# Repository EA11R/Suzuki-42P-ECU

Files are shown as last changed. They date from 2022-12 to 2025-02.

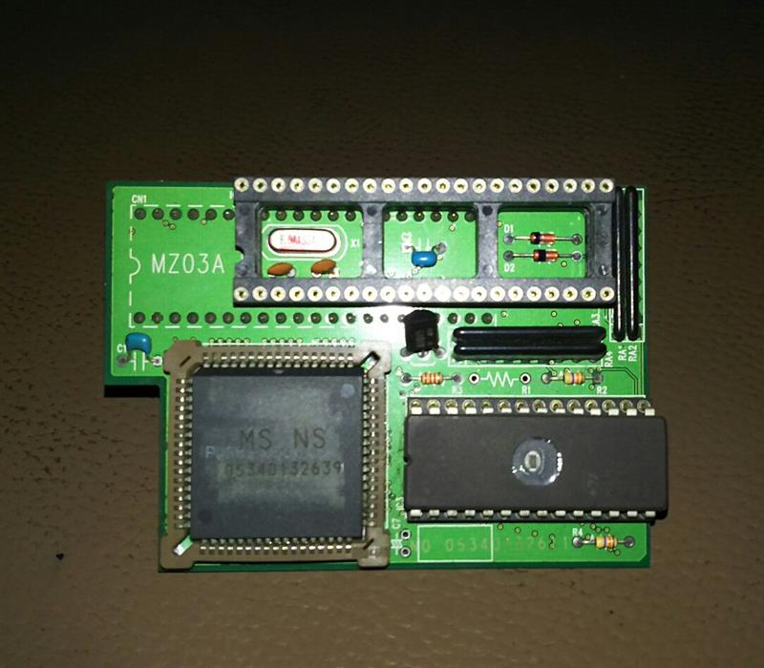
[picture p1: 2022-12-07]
TECHTOM/IMG_0491.JPG

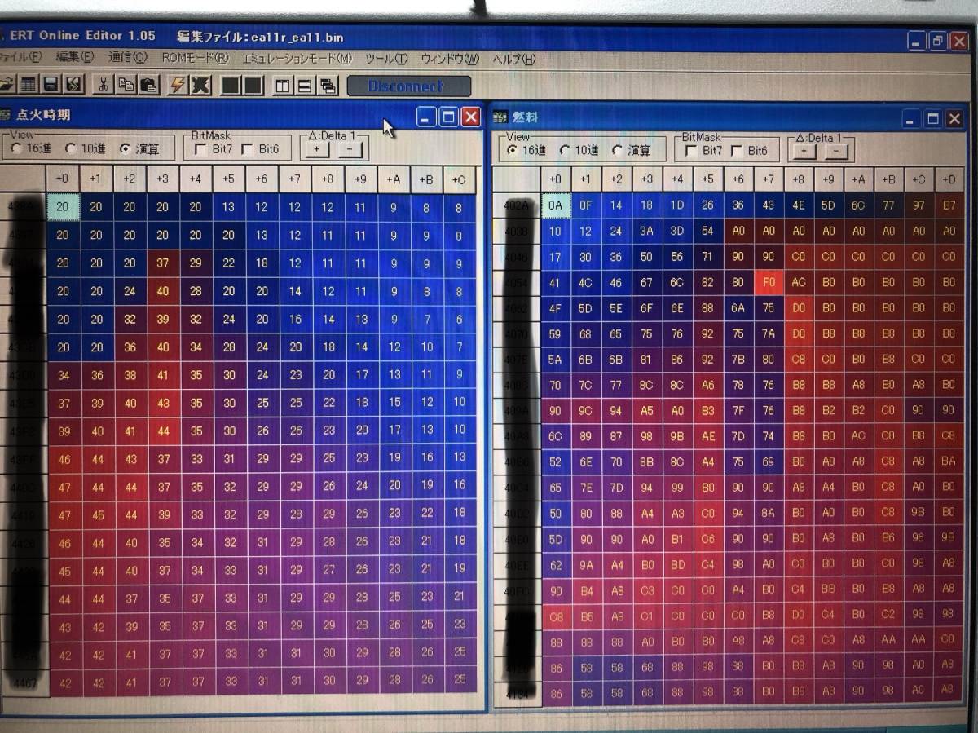
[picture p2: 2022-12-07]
TECHTOM/i-img1200x899-1564741742y9fy37383216.jpg

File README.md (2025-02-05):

# Suzuki-42P-ECU
The #1 source of Suzuki mask MPU information and resources 
 ## image of board 
 
 i-img1200x903-1666231880i3cpzc833943

 the board utilzes a 8-bit cpu which is masked it's believed to be close 
 
 > the pinout has been previously figured out by (rhinopower) 
 www.rhinopower.org/ECUs/RomReader/Romreader.html
 
 ## pinout of the cpu 
  IMG_0691_result

## about [*IC101*]
the raw sensor input connects to IC101 before being converted to digital signals 
and sent to CPU on the Right side of the IC the raw inputs could be sniffed as a 0-5v
analog signal.

> this is a pinout of the ecu pulled over by a scope and some testing 
I took the neccesary pins of it to work and left over things such as temp sensors 
it can be pulled out of the ecu but I honestly can't tell how to turn that digital signal into numbers without further testing
the IC before it however has a gradiant signal of voltage via the variant resistance of the temp thermos 
I have took the neccesary pins to hook the ECU alongsite a daughter card that uses speeduino 

## Current Daugtercards on sale
   MTR40BB : https://buyee.jp/item/yahoo/auction/u1052820291
   
   QSF313_F6A : https://github.com/EA11R/Suzuki-42P-ECU/tree/main/QSF_ADD_ON_BOARD

## Possible piggy-back ECU's
- E-manage (TRUST)

- HKS F-con (ALL)

- Speeduino ( can be standalone with some changes)

- any ECU that can get a squarewave signal and a choice of cylinders.
Current ("Free of charge") project

- an open source ECU adapter for speeduino boards & harness how to and links to purchace parts 

- Adapter PCBS for popular ecus with an added pip373 slot for distrubtor ignition!

- Modren Daughtercard using oem CPU + speeduino (atmega 2560) , for better ignition timing , full fuel control

> Prepare for Piggyback install : 


 - 1 Cut the resistor where I have the solder joint from the middle so you can Undo if you wish. 
     then pass the wires trough the case holes
  
 -  2 Solder the wire onto the remaining of the resistor leg. & lift it up to keep space * this will be your "out wire" from stock to aftermarket
 
  - 3 shrink tube the resistor is a good countermeasure just incase the resistor vibrates back into place , any insulator is fine.
 
 -  4 solder a IN wire in the remaining of the other side. ( connect the wire coming from aftermarket to your stock ecu)
  
  >  the rest of the information will be on each independant ecu catagory with it's own install guide.

## Repair 
- As far as repair goes within the suzuki ecu
if you manage to burn the cpu or the IC101 you need another suzuki ecu as a donor to fix that 
otherwise all other parts can be found off shelf 
the similar ICs are AD chips.

## My PNP Card Design 
converts the OEM stock ECU into a tuneable 
ECU and adds a Addtional injection channel 
to convert fueling into fully sequential

Features:

-Internal MAP option 

-wideband support 

-Ignition control (optional)

-Bluetooth 

-Data logging (bluetooth or usb)



## PDF Resources & Notes

| ECU | PDF/DIR  |
| --- | --- |
| QSF_F6A |[Directory](QSF_ADD_ON_BOARD/readme.md)
| HKS F-CON IS Pinout |[Click Here](HKS_F_CONV_&_IS/F-conIS.jpg) |
| HKS F-CON IS Installion Notes |[Click Here](HKS_F_CONV_&_IS/installation%20notes.md) |
| E-Manage (TRUST) |[Directory](E-manage/) |
| MCU & EPPROM's |[Directory](Datasheet/)
| MTR40BB |[Directory](MTR40BB%20INFORMATION/)
| Speeduino |[Directory](speeduino/)
| Distributor_wheel |[Directory](Distributor_Modification/readme.md)

So lets see where this project goes and the documentation with it shall we 

**Qatif Speed Factory , Saleh.M**

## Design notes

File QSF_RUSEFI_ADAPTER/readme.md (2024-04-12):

## RUSEFI UAEFI BASED SUZUKI EMS 
as rusefi expanded into making better and better ecus over the years , they've released the affordable verison of their lineup and that is way over what the cappuccino needs to run since it's a 6x6 ecu
therefore many of the outputs can be reutilized for other things and I took advantage over the fact to create a true "ULTRA AFFORDABLE CAPPUCCINO ECU" without going low on features 

## For people with bare stock cars
just plug the ecu and turn the key it will function as is and perform superior to stock it will come with a base tune that can run the car 
daily , and without the annoying fuel cut , engine rev limiter will come configured @9000 rpm to cut spark only and without any boost limitation 
or speed however with needs to upgrade turbo , injectors etc , you can dive into the depths of this manual.

## for nerds 
you can get the adapter from me and solder the ecu board from RUSEFI yourself 
I recently changed my pin size to arduino (0.8MM) on adapter side due to 1.14MM pins being difficult to source and expensive 
would increase cost by 60$

## IMAGE OF BOARD





## COP HARNESS EXPLAINED 


## WARNING 
please use orignal IG power to power ur coil pack harness instead of direct ecu feed 
don't use 12V on ecu extra plug to feed it with power as I only use them for testing

## Wiring order
**IGN 1 = CLY 1** 

**IGN 2 = CLY 2**

**IGN 3 = CLY 3**

each number goes to it's co-responding cylinder don't be afraid to mismatch because it can be managed in software 
for GND of coils it should be grounded somewhere in the engine , anywhere you wish as long as it's a good ground 

## TACHOMETER
for tach signal I suggest some aftermarket cop tach adapters 
such as this if you're running "smart coils without a external ignitor" https://www.ebay.com/itm/142171581596 

and one such as this https://www.autosportlabs.com/product/tach-adapter/ for dumb coils!

**if you're running dumb coils with a external ignitor , you simply connect the coil minus side of ignitor and not the ecu signal side**
that piece will collect all grounds and will send a signal back to your orignal tach without taking it out and modfiying it 
the cappuccino tachometer is similar to many toyotas of that era since it's denso made!
before connecting "TACH" to your orignal brown wire (coil ground) cut the IGN jumper shown below


## WARNING 
DO NOT AT ANY CIRCUMSTANCE PLUG A DUMB COIL DIRECTLY INTO THE COP HARNESS USE A IGNITOR BOARD BOUGHT NEW OR SALVAGED FROM A YARD , HERES SOME OPTIONS SO YOU DON'T SMELL FUNNY ELECTRONICS OR LOSE 300$ IN THE BIN 
## IGNITOR SUGGESTIONS 
 

Nissan igntiors

 

toyota igntior 



bosch (0 227 100 200) 3 channel



basically any ignitor set that can fire 3 coils would be ok for smart coils you won't need a ignitor obviously 

## IGN JUMPER 


**make sure to cut jumper made here , and remove solder from the SMD jumper , the THT jumper is there if you somehow manage to ruin the SMD jumper however it's nice to have both closed when running stock coil to insure it's getting a good signal** 

orignal harness side coil plug 
https://www.aliexpress.com/item/1005002422920931.html
needed to make a COP plug , source whatever coils u want ur self , and take care of the bracket

## WARNING 

if you don't cut IGN jumper or remove IGN#1 wire from ecu plug this before install of coil packs you can risk damage to your tach or ecu while installing tachometer adapter 
tach adapters have voltage spikes up to 60V and I don't suggest back feeding it into your ignition transistor as it shouldn't share the signal with IGN#1 
anymore

## AUX 1 (one of 3 AUX WIRES across the board)
it's a gauge input bundled with the COP plug you can use that to put any analog gauge u wish into ur ecu
if ur running a stock setup and want to have a full digital cluster I suggest using it for fuel level!
AUX1 can be used for a external wideband that isn't CAN based but I suggest using it for something more useful
such as oil temp or pressure along with the other AUX gauges
## Ask for help you're not superman!
again if you don't have knowledge in wiring don't be afraid to ask me or consult your local wiring/ecu speicalists 
just hand them this information and they will certianly understand why and how!

## CAS HARNESS EXPLAINED 



as simple as it gets wire each one into it's counterpart in the CAS sensor on ur daewoo distributor 



## KNOCK SENSOR (IN CAS HARNESS BECAUSE IT'S CLOSE TO THE BOTTOM OF THE ENGINE)
for knock sensor check the diagram of whatever sensor ur using 

wire signal to KNOCK_IN

wire ground to GNDA 

## CAN BUS HARNESS 



CAN + , CAN - can be used to wire a external wideband such as AEM Series X , you can certianly use the onboard wideband if you don't want/need a gauge

BTN2 (ORIGNALLY USED FOR A/C) (can be reutilized for race cars) , BTN3,BTN1 can be used as a clutch switch or any kind of button to activate anything 

**BUTTONS (GROUND BASED SWITCH OR BUTTON ONLY)**

## E-Throttle + TPS information 


| PIN | FUNCTION |
| --- | --- |
| DC1 +  | Throttle motor + |
| DC1 - | Throttle motor -  |
| TPS1  | TPS SIGNAL|
| TPS2  | TPS SIGNAL(only E throttle uses two tps)|
| GNDA | I think ground O_0 but for sensor (use for tps) |
| 5V | I think FIVE VOLTS use for tps power |
| fun fact | TPS 5V being connected with any 12v wire will kill ur ecu |

| PIN | FUNCTION |
| --- | --- |
| PPS1  |Primary pedal output|
| PPS2 | secondary pedal output|

| EXTRA PIN | FUNCTION |
| --- | --- |
| LSW1  |LOW SIDE OUT (can used for fan relay)|
| BTN1 | BUTTON OR SWITCH INPUT (GROUND BASED ONLY) |



| EXTRA PIN | FUNCTION |
| --- | --- |
| IGN5 (TACH)  |TACHOMETER OR WHATEVER OUTPUT U WANT|
| AUX3 | ANALOG GAUGE INPUT (0-5V) |

**IF YOU EVER WANTED STEPPER IDLE**

| DC PIN | FUNCTION |
| --- | --- |
| DC2+  |STEPPER +|
| DC2- | STEPPER- |

## NEW ECU PINOUT AND EXTRAS 



the unused pins in the harness are now INJ3 (For sequential use) and FLEX (Flex fuel sensor) 
EL1 , EL2 are dropped from harness (unconnected) 
EGR No longer used (always off) 

## supported Triggers 

| TRIGGER | RECOMMENDED |
| --- | --- |
| EA11R STOCK 3 TOOTH |works but very low res (single coil only) |
| Daewoo Distributor | recommended for single coil and COPs|

## for nerds read: 

| Distributor_wheel |[Directory](https://github.com/EA11R/Suzuki-42P-ECU/blob/main/Distributor_Modification/readme.md)|
| --- | --- |

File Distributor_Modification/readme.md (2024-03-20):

Modification of the Disitributor or installation of a crank trigger wheel is a basic Requirment of Running a Aftermarket EFI unit on your suzuki
sometimes those options could be a little expensive so heres some options you can reside to!

[OPTION #1] a replacment trigger wheel by link JP

Distrubtor wheel 24-1 Link JP (KTD F6CG) 
 
 F6CG TRIGGER(FITS INSIDE OEM CASE)

[OPTION #2] Honda 24 Distributor wheel modification 
Parts needed:

Honda D ,K series Distrubtor from junk
Hall crank sensor 
Cherry GS101205 HALL effect sensor 
Note : you need a 1k ohm resistor between VCC (5v+) and out (Signal) 

* you might be able to stay with the stock VR signal pickup but i have not tested if it could read a stable signal!
* wouldn't hurt to try either.





[OPTION #3] a TDC tooth on cam ( check the E-manage Section)

[OPTION #4] Crank wheels (some kind people within this community have done free files)
I will get time to do a write up on those too!

[OPTION #5] Daewoo matiz distributor 
it fits on the cappuccino directly , the cappuccino cap also fits over 
can use a R32 crank sensor if you remove it off the case it bolts right on 
it can also use a AEM 24-1 disc if you wish!
my rusefi based ecu can support stock GM trigger

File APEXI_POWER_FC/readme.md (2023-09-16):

Converison of RB26 Harness to work with the F6A engine 

Basic knowledge about how similar inline 6 engines are to inline 3

I6 : Piston 1,6 2,5 3,4 are paired together 
I3 : Piston 1,3,2 each on it’s own 

Firing order of an I6: 1-5-3-6-2-4 every cycle 

Firing order of an I3 : 1-3-2 every cycle 

so we understand that the I6 fires 6 times every full rotation
and the inline 3 fires 3 times every full rotation
so those aren’t matching in terms of fire

However if we skip 1 coil (piston in the cycle ) we get the half

(1-skip-3-skip-2-skip) we right now have a suitable ignition! 

IMG_C7B1C2669041-1

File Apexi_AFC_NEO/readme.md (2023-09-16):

Piggy back solution to trick the map sensor into reducing/adding more fuel 
can be helpful when installing larger injectors on stock ecu!
or simply for adding more fuel to your engine for more boost without the hassle 
or price of a standalone or chipped (suzuki sport ecu)

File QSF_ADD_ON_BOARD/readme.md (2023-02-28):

## Details about my Daughtercard for the F6AT ecu (K1)



Since the simplcity of the stock ecu Throttle switch I've decided to link it using a 5v signal from the actual ecu pinout so only WOT would effect the signal however if you wish to cancel this and add a virable nissan TPS you could unsolder the JP2 and connect it to the TPS pin shown within this photo
this should allow the tps to be utilized to be used for accel enrichment 

the map sensor can be connected via ADC chip but the better choice is to use the internal map sensor to control fueling in the system

#R504 can be connected to IG1 (**H1** on the board) to control the Ignition Advance however deleting the fuel cut is what is needed to add more boost 

there's extra circuit that could be built under the MPU to add a third injection channel to fully sequentially control the fuel on the engine 
so it becomes a single injection channel for each injector instead of the paired wire #20 on the oem harness 
------------------------------------------------
 **FEATURES** 
------------------------------------------------

1- On Board boost control ( requires a external solenoid) 
Ran via PWM signal 

2- Wideband support over the same wire (OX signal) 

3- Third Injection Channel 

4- Usage of full range TPS for accel enrichment 

5- External tach RPM wire (12v)

------------------------------------------------
**Third Injection channel**
------------------------------------------------
A Twin wire harness can be wired straight from the board to the injector #3 
This modification will convert the injection system to fully sequential 

** Ignition Advance control **
However it's very limted and not actually that useful but it's still possible 
I strongly advise just sticking to moving the distrubutor to adjust the timing or
buying viarable cam gears however adjusting small increments on higher boost could be done
over computer

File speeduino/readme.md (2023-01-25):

](https://wiki.speeduino.com/en/boards/V04) WIRING PINOUT

KEEPING THE RESISTOR IN PLACE AND SOLDERING THE SAME SPOT AS THE EXAMPLE IMAGE WILL ELEMINATE SPEEDUINO IGNTION CONTROL!
USEFUL WHEN RUNNING A EXTERNAL CDI OR JUST ADJUSTING FUEL.
IG_SPEEDUINO

this is the way to wire it up with ignition control

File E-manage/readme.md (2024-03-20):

| Title | Link |
| --- | --- |
| TDC adjustable cam trigger + E-manage setup information  |  [Click Here](https://factoryryo.web.fc2.com/factoryryo/specialtune/specialtune32.htm) 
| Japanese wiring diagram |  [Click Here](https://minkara.carview.co.jp/userid/17619/blog/1461248/)  |
| Jumper Informaiton for E-MANAGE BLUE |  [Click Here](https://minkara.carview.co.jp/userid/522838/car/457922/1506196/note.aspx) |

note Injectors are flipped 10# , 20# I had my harness plug flipped and this was based on a previous install
so on a normal car #10 is 1,2 and #20 is cly 3 on it's own! 

**flip injector light blue and yellow if you're following this for a install**



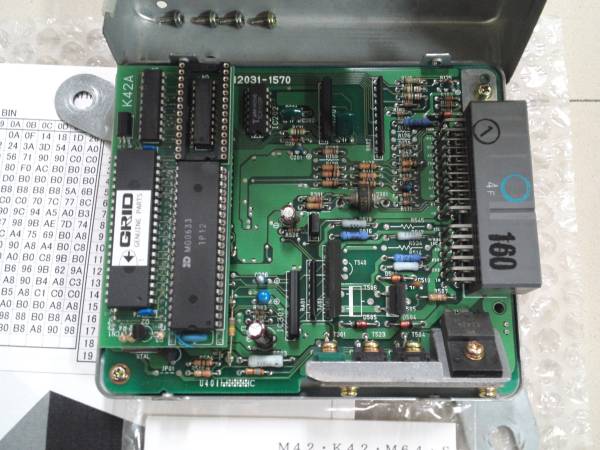
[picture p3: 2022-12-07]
GRID/d162023006.2.jpg

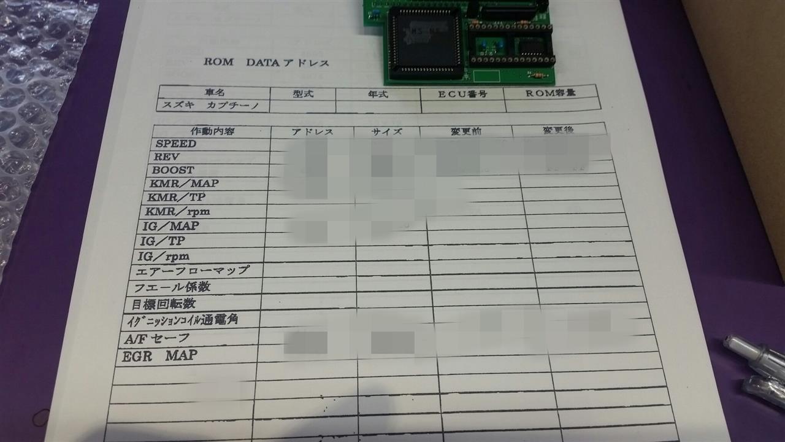
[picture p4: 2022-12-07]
TECHTOM/2167e978b1.jpg

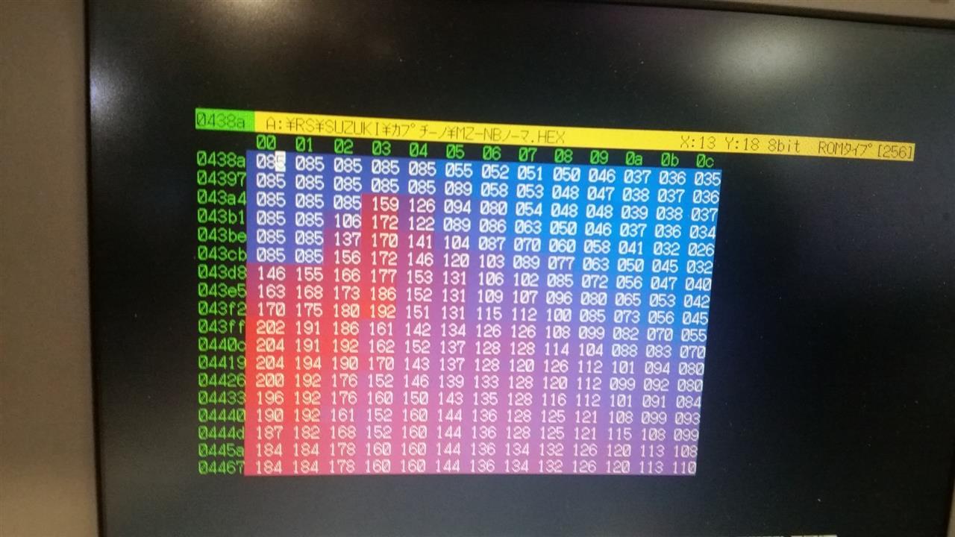
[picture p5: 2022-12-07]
TECHTOM/cb408cf9b0.jpg

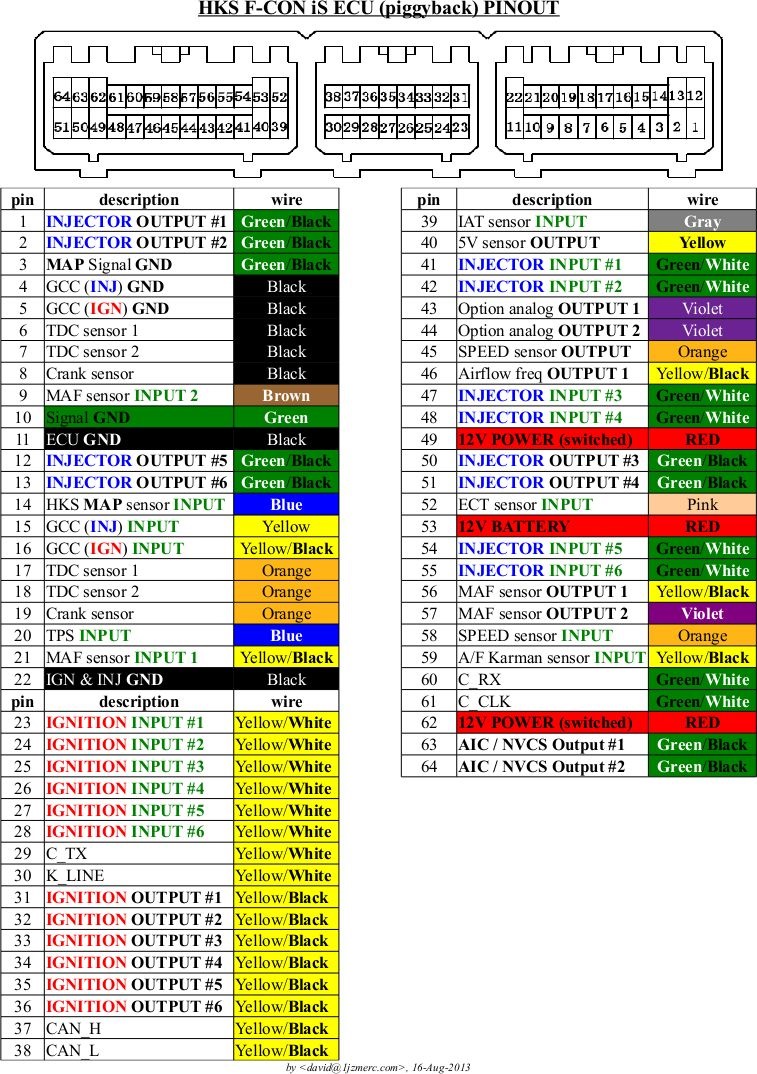
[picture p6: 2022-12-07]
HKS_F_CONV_&_IS/F-conIS.jpg

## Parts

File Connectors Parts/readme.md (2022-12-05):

## 22 PIN CONNECTOR 174913-6 ,174515-1
https://aliexpress.com/item/4001286921974.html 

## 12 PIN CONNECTOR  917989 , ? 
https://aliexpress.com/item/1005003760250270.html

## 34 PIN MAIN 
175444-6 TYCO 34 POSITION MULTILOCK I/O HYBRID CONNECTORS
https://aliexpress.com/item/1005003569743487.html

## PREBUILT EXT HARNESS 
https://buyee.jp/item/yahoo/auction/c1073995630

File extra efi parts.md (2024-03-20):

Distrubtor wheel 24-1 
Link JP (KTD F6CG)
http://www.linkecu.co.jp/products/detail/71

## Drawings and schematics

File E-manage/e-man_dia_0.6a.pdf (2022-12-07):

# は割り込み

# e-manage Ultimate wiring diagram

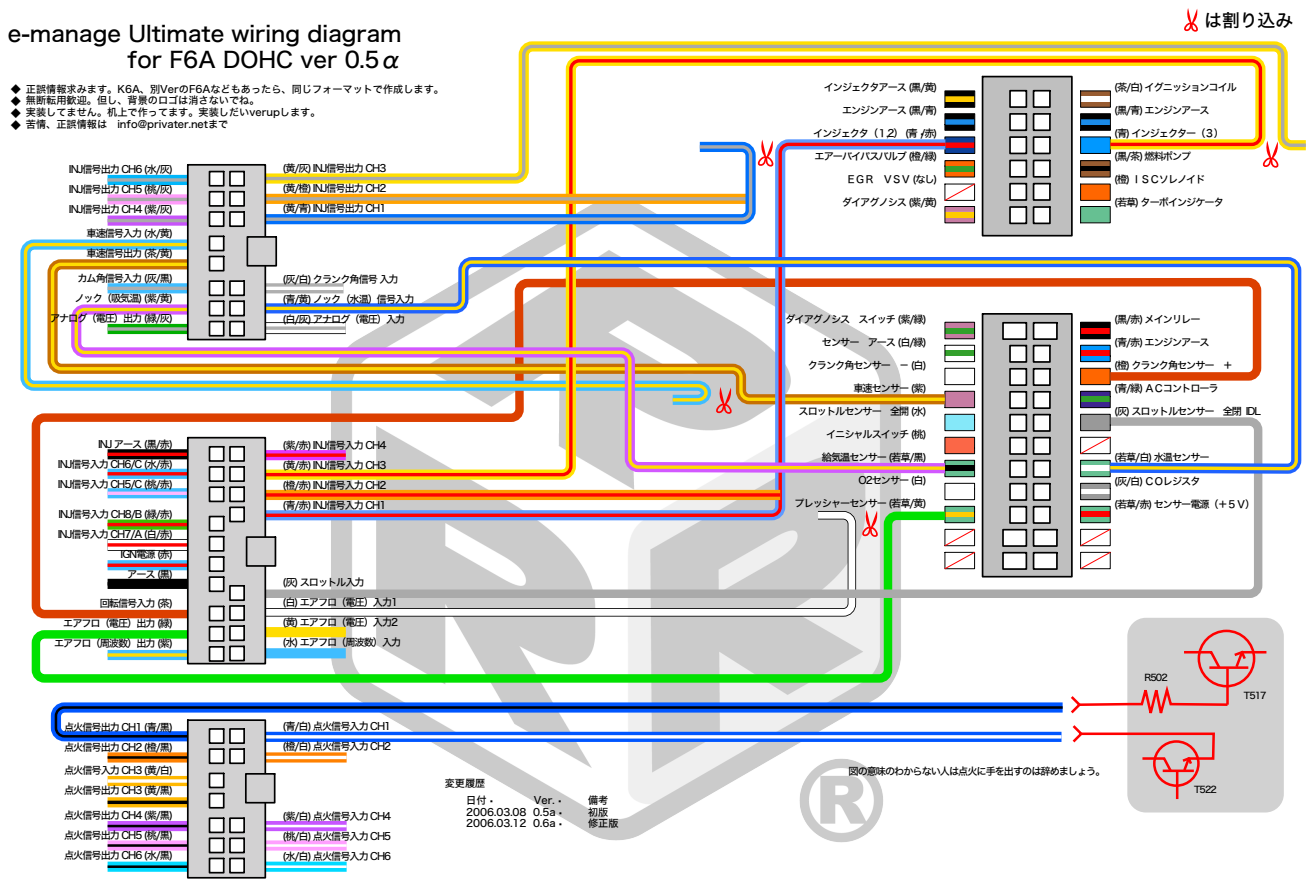
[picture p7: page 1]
図の意味のわからない人は点火に手を出すのは辞めましょう。; インジェクタアース(黒/黄); エンジンアース(黒/青); インジェクタ（１,2）(青/赤); エアーバイパスバルブ(橙/緑); ダイアグノシス(紫/黄); (茶/白)イグニッションコイル; (黒/青)エンジンアース; (青)インジェクター（３）; (黒/茶)燃料ポンプ; (橙)ＩＳＣソレノイド; (若草)ターボインジケータ; ダイアグノシス スイッチ(紫/緑); センサー アース(白/緑); クランク角センサー －(白); 車速センサー(紫); スロットルセンサー 全開(水); イニシャルスイッチ(桃); 給気温センサー(若草/黒); O2センサー(白); プレッシャーセンサー(若草/黄); (黒/赤)メインリレー; (青/赤)エンジンアース; (橙)クランク角センサー ＋; (青/緑)ＡＣコントローラ; (若草/白)水温センサー; (灰/白)ＣＯレジスタ; (若草/赤)センサー電源（＋５Ｖ）; (紫/白)点火信号入力CH4; (桃/白)点火信号入力CH5; (水/白)点火信号入力CH6; (青/白)点火信号入力CH1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

for F6A DOHC ver 0.5α

正誤情報求みます。K6A、別VerのF6Aなどもあったら、同じフォーマットで作成します。
無断転用歓迎。但し、背景のロゴは消さないでね。
実装してません。机上で作ってます。実装しだいverupします。
苦情、正誤情報は info@privater.netまで

ＥＧＲ ＶＳＶ(なし)

カム角信号入力(灰/黒)
ノック（吸気温)(紫/黄)
アナログ（電圧）出力(緑/灰)

(灰/白)クランク角信号入力
(青/黄)ノック（水温）信号入力
(白/灰)アナログ（電圧）入力

(灰)スロットルセンサー 全閉 IDL

(灰)スロットル入力
(白)エアフロ（電圧）入力1
(黄)エアフロ（電圧）入力2
(水)エアフロ（周波数）入力

エアフロ（電圧）出力(緑)
エアフロ（周波数）出力(紫)

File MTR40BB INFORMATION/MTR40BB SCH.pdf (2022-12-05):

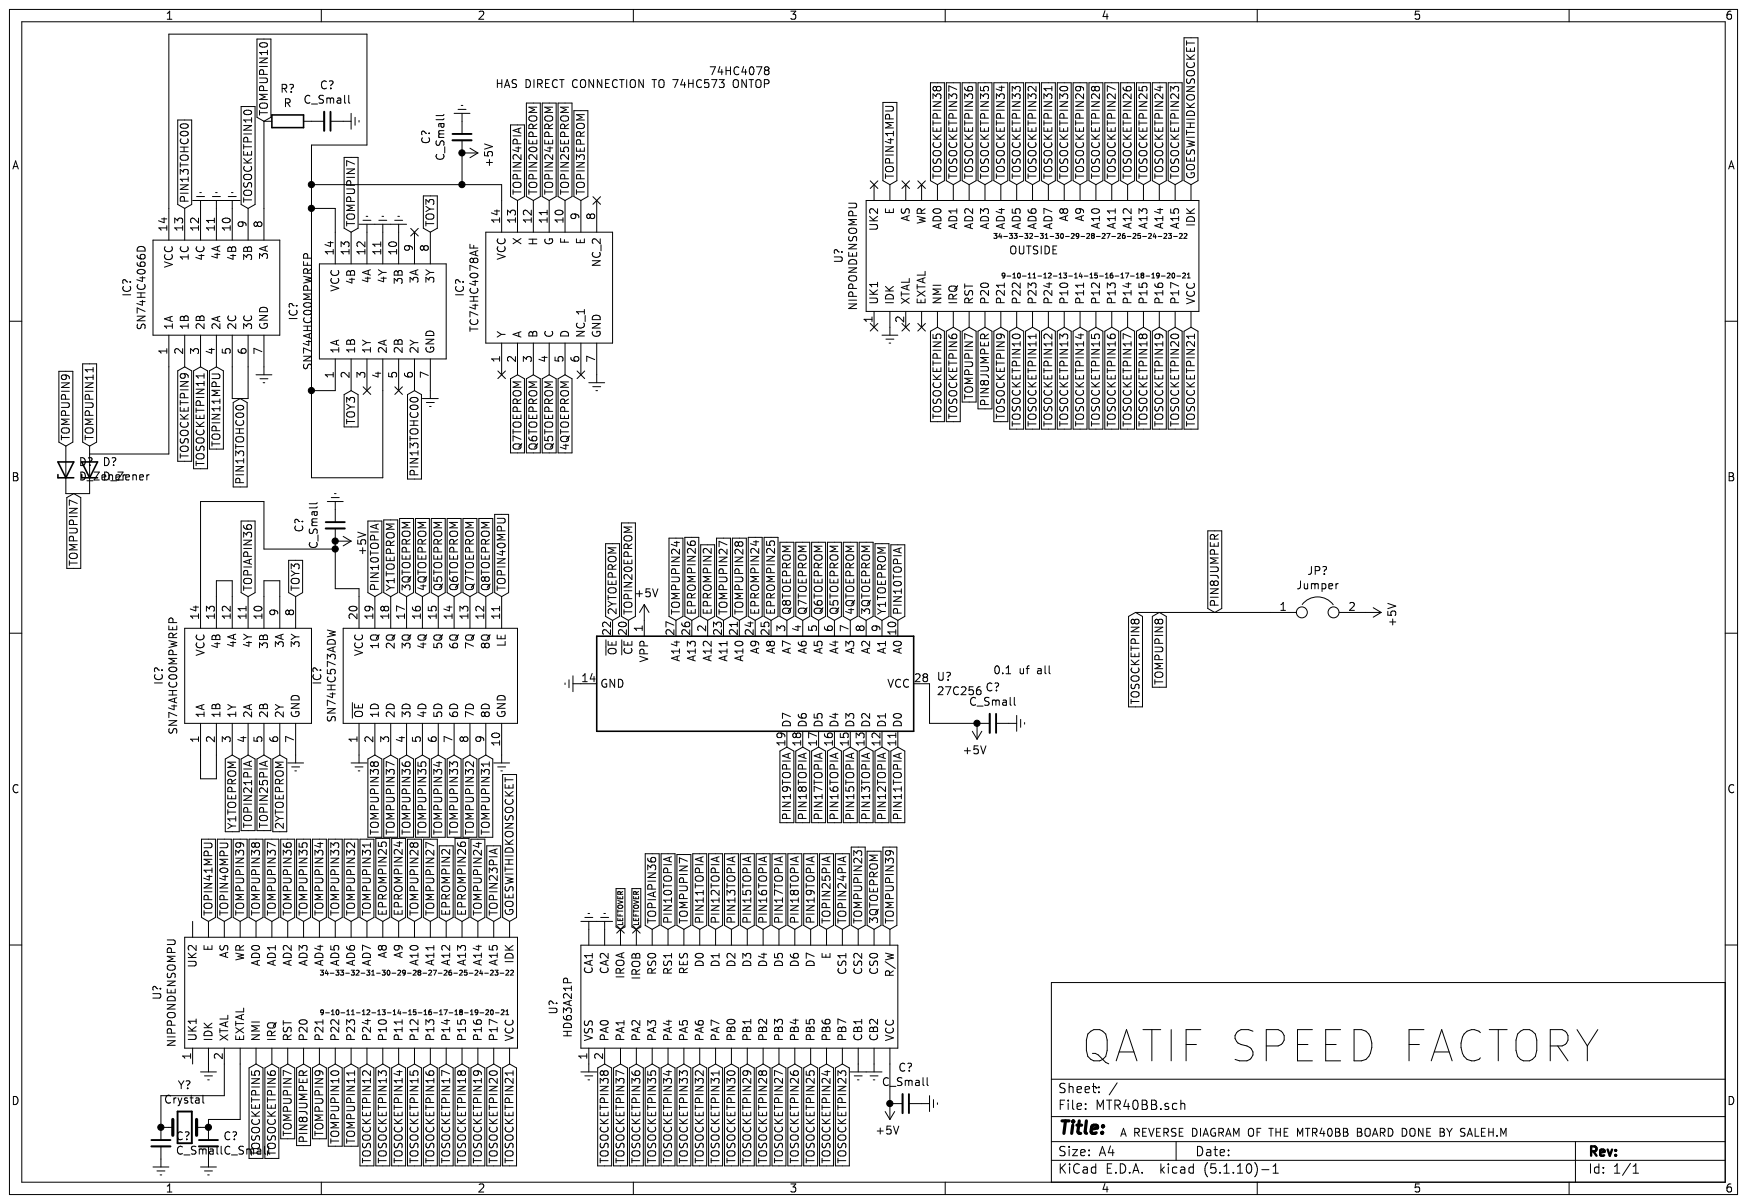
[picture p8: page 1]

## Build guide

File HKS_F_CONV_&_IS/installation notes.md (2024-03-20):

on most of my diagrams my injector wires are flipped because I messed on my harness and forgot to flip them back and drew those diagrams based on my own harness 

so please remember that #10 is 1 , 2 and #20 is 3 on it's own

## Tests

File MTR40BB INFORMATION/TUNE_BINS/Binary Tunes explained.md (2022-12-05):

## FILE TYPE 

Those are the files that are normally uploaded onto the 27C256 Which are binary and require a chip burner capable to upload roms

## TOOLSET FOR MODIFYING TUNES 

1- a knowledge of some offset or / an actual ROM emulator to do real time tuning 

2- a rom burner 

3- a head gasket or an actual tuner lol 

4- a friend with a tuned chip to copy.

## KNOWN WAYS OF READING ROM 
www.rhinopower.org/ECUs/RomReader/Romreader.html

I never tried to put a blank chip in the MTR40BB to see if it actually writes it if it's blank

But If I ever have the chance to get my hands on a N1 , N2 ECU

I would surely build a rom Reader for that!
